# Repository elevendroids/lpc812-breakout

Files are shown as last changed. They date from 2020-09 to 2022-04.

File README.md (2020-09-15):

# LPC812 Breakout Board (Rev. A)

Small breakout board designed for the [LPC812](https://www.nxp.com/docs/en/data-sheet/LPC81XM.pdf) ARM Cortex-M0+ microcontrollers from NXP

## Features

- minimal subset of components, no power regulation etc.
- optional external crystal - if not used, its GPIO pins can be connected to the user header by soldering relevant 0R resistors (see schematic)
- two buffered user LEDs, connected to the header - no reserved GPIOs
- reset button
- standard 0.05" pitch SWD programming header, SWD signals also present on the pin headers

Designed in KiCad 5.1.6

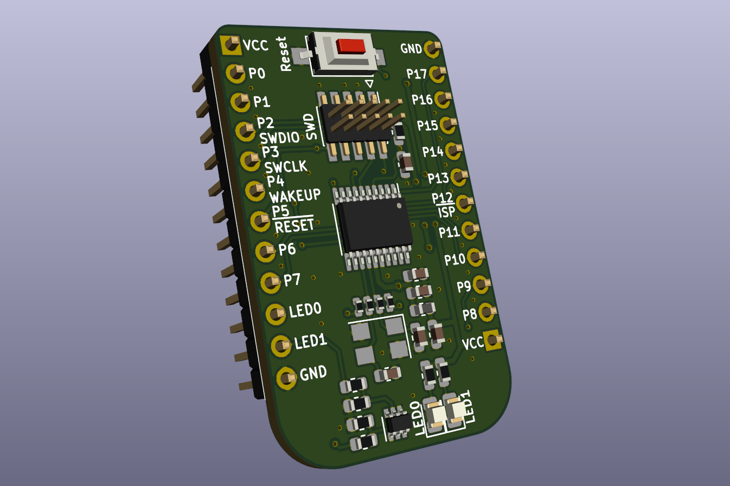
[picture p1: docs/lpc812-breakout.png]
PCB Render


Schematic: [PDF](docs/lpc812-breakout.pdf)

License: [CC BY-SA 4.0](https://creativecommons.org/licenses/by-sa/4.0/)

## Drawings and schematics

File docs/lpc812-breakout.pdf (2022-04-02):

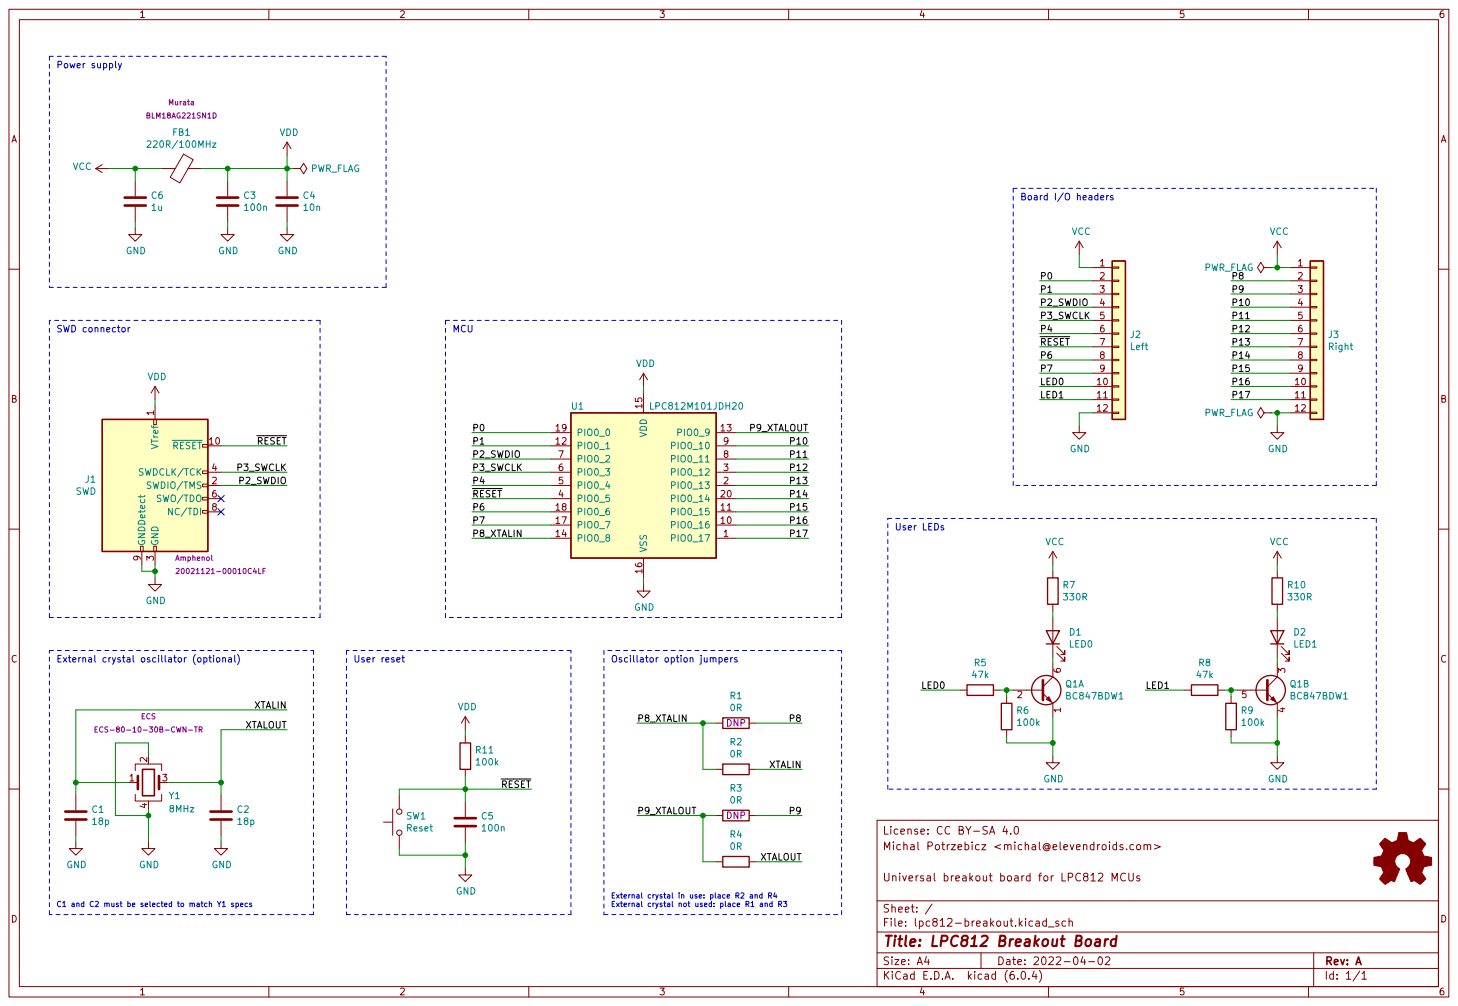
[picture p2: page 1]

3 SWDCLK/TCK 4 SWO/TDO 6 NC/TDI 8 GNDDetect 9

External crystal oscillator (optional)

File: lpc812-breakout.kicad_sch Sheet: / Universal breakout board for LPC812 MCUs Michal Potrzebicz <michal@elevendroids.com>

Id: 1/1 Title: LPC812 Breakout Board

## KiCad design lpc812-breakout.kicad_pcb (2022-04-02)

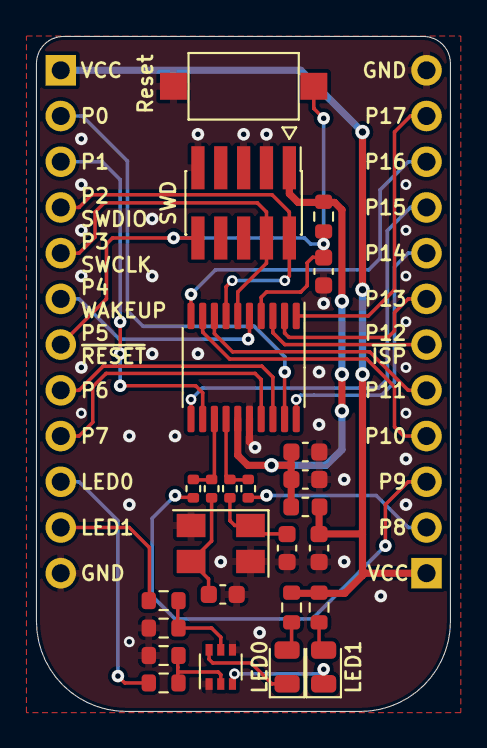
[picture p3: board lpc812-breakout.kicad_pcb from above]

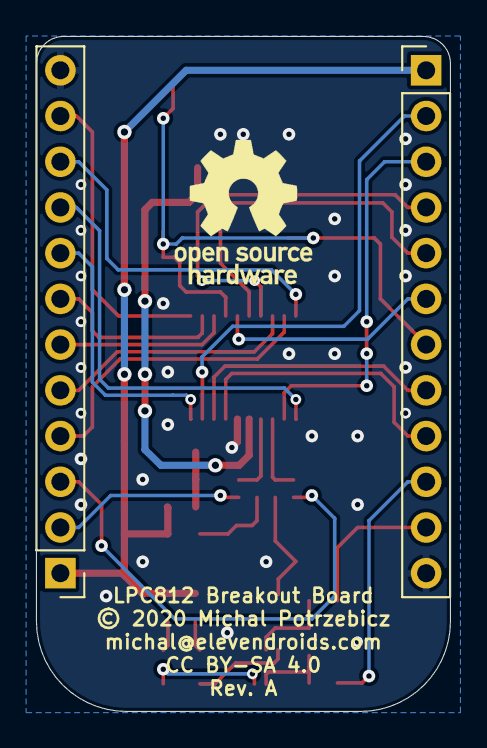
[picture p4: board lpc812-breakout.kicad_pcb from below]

Board: 2 copper layers, 23.0 x 37.5 mm, 27 parts (2 on the bottom side), 33 nets.

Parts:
C1, C2: 18p; C_0603_1608Metric
C3, C5: 100n; C_0603_1608Metric
C4: 10n; C_0603_1608Metric
C6: 1u; C_0603_1608Metric
D1: LED0; LED_0805_2012Metric
D2: LED1; LED_0805_2012Metric
FB1: 220R/100MHz; L_0603_1608Metric
J1: SWD; PinHeader_2x05_P1.27mm_Vertical_SMD
J2: Left; PinHeader_1x12_P2.54mm_Vertical
J3: Right; PinHeader_1x12_P2.54mm_Vertical
Q1: BC847BDW1; SOT-363_SC-70-6
R1, R2, R3, R4: 0R; R_0402_1005Metric
R5, R8: 47k; R_0603_1608Metric
R6, R9, R11: 100k; R_0603_1608Metric
R7, R10: 330R; R_0603_1608Metric
SW1: Reset; SW_SPST_CK_RS282G05A3
U1: LPC812M101JDH20; TSSOP-20_4.4x6.5mm_P0.65mm
Y1: 8MHz; Crystal_SMD_5032-4Pin_5.0x3.2mm

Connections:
/LED0: J2.10, R5.2
/LED1: J2.11, R8.2
/P0: J2.2, U1.19 (PIO0_0)
/P1: J2.3, U1.12 (PIO0_1)
/P2_SWDIO: J1.2 (SWDIO/TMS), J2.4, U1.7 (PIO0_2)
/P3_SWCLK: J1.4 (SWDCLK/TCK), J2.5, U1.6 (PIO0_3)
/P4: J2.6, U1.5 (PIO0_4)
/P6: J2.8, U1.18 (PIO0_6)
/P7: J2.9, U1.17 (PIO0_7)
/P8: J3.2, R1.1
/P8_XTALIN: R1.2, R2.2, U1.14 (PIO0_8)
/P9: J3.3, R3.1
/P9_XTALOUT: R3.2, R4.2, U1.13 (PIO0_9)
/P10: J3.4, U1.9 (PIO0_10)
/P11: J3.5, U1.8 (PIO0_11)
/P12: J3.6, U1.3 (PIO0_12)
/P13: J3.7, U1.2 (PIO0_13)
/P14: J3.8, U1.20 (PIO0_14)
/P15: J3.9, U1.11 (PIO0_15)
/P16: J3.10, U1.10 (PIO0_16)
/P17: J3.11, U1.1 (PIO0_17)
/XTALIN: C1.1, R2.1, Y1.1
/XTALOUT: C2.1, R4.1, Y1.3
/~RESET: C5.1, J1.10 (~RESET), J2.7, R11.2, SW1.2, U1.4 (PIO0_5)
GND: C1.2, C2.2, C3.2, C4.2, C5.2, C6.2, J1.3 (GND), J1.5 (GND), J1.9 (GNDDetect), J2.12, J3.12, Q1.1 (E1), Q1.4 (E2), R6.2, R9.2, SW1.1, U1.16 (VSS), Y1.2, Y1.4
unnamed: D1.1 (K), Q1.6 (C1)
unnamed: D1.2 (A), R7.2
unnamed: D2.1 (K), Q1.3 (C2)
unnamed: D2.2 (A), R10.2
unnamed: Q1.2 (B1), R5.1, R6.1
unnamed: Q1.5 (B2), R8.1, R9.1
VCC: C6.1, FB1.2, J2.1, J3.1, R7.1, R10.1
VDD: C3.1, C4.1, FB1.1, J1.1 (VTref), R11.1, U1.15 (VDD)

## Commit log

2020-09-15 Schematic cleanup
    [lpc812-breakout.kicad_pcb, lpc812-breakout.sch]
2020-09-15 Added readme and a PCB render
2020-10-09 Swapped SWDCLK and SWDIO - D'oh!
    [lpc812-breakout.kicad_pcb, lpc812-breakout.sch]
2020-10-09 Swapped LED0 with LED1 on the PCB (wrong labels, d'oh!)
    Rerouted the Reset and SWD tracks
    [lpc812-breakout.kicad_pcb]
2020-10-09 Updated dates, iBOM and the schematic PDF
    [lpc812-breakout.kicad_pcb, lpc812-breakout.sch]
2020-10-12 PCB tweaks, updated documentation
    - made the PCB a bit narrower: 24 mm -> 23 mm
    - added/moved some of the GND vias
    - updated docs and the BOM
    [lpc812-breakout.kicad_pcb, lpc812-breakout.sch]
2020-10-12 More GND vias
    [lpc812-breakout.kicad_pcb]
2022-04-02 Project upgrade to KiCad 6
    [lpc812-breakout.kicad_pcb, lpc812-breakout.kicad_sch, lpc812-breakout.sch]

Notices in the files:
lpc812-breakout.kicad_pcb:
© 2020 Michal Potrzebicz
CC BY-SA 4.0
